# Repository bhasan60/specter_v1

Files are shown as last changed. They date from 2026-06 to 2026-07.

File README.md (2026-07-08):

## The Story Behind Specter V1
Welcome to the Specter V1! This is a custom 9-key macropad that I designed from the ground up. I wanted a dedicated board just for fun and maybe some custom shortcuts, but more importantly, I wanted to challenge myself to handle every single step of the hardware and software design process.

While I have a lot of experience with 3D modeling in Onshape, designing a custom 2-layer PCB from scratch in KiCad was a massive learning experience for me. It was fun though :)

## Hardware & Features
* **The Brain:** The whole board is powered by a Seeed Studio XIAO RP2040.
* **Inputs & Control:** It features 9 mechanical switches and a tactile rotary encoder.
* **Display:** I integrated a small OLED screen at the top to display certain GIFs or random stuff.
* **Custom PCB:** The board is a custom 2-layer design. To give it a personal touch, I added a custom New York Knicks logo to the front silkscreen to rep my city!
* **Enclosure:** The physical case is a custom two-part 3D-printed shell I modeled in Onshape. It is designed to fit snugly around the components and is secured together using M3 screws.
* **Firmware:** The macropad is fully programmable using QMK. 

## Screenshots
Overall Hackpad:



Schematic:



PCB:




Case:


I plan on fitting the two parts of the case together by threading the M3 screws into them.

## Bill of Materials (BOM)
* 1x Seeed Studio XIAO RP2040
* 9x Mechanical Switches
* 9x 1N4148 Diodes
* 1x Rotary Encoder (with push-button)
* 1x OLED Display
* 3D Printed Case (Top and Bottom)

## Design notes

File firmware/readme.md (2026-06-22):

# specter_v1

specter_v1

*A short description of the keyboard/project*

* Keyboard Maintainer: [Belal Hasan](https://github.com/bhasan60)
* Hardware Supported: *The PCBs, controllers supported*
* Hardware Availability: *Links to where you can find this hardware*

Make example for this keyboard (after setting up your build environment):

    make specter_v1:default

Flashing example for this keyboard:

    make specter_v1:default:flash

See the [build environment setup](https://docs.qmk.fm/#/getting_started_build_tools) and the [make instructions](https://docs.qmk.fm/#/getting_started_make_guide) for more information. Brand new to QMK? Start with our [Complete Newbs Guide](https://docs.qmk.fm/#/newbs).

## Bootloader

Enter the bootloader in 3 ways:

* **Bootmagic reset**: Hold down the key at (0,0) in the matrix (usually the top left key or Escape) and plug in the keyboard
* **Physical reset button**: Briefly press the button on the back of the PCB - some may have pads you must short instead
* **Keycode in layout**: Press the key mapped to `QK_BOOT` if it is available

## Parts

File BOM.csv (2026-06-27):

Quantity | Component | Notes
1 | Seeed Studio XIAO RP2040 | Main microcontroller
9 | Mechanical Switches | Keyboard switches
9 | 1N4148 Diodes | Matrix diodes
1 | Rotary Encoder (with push-button) | Encoder with click
1 | OLED Display | Screen
1 | 3D Printed Case (Top and Bottom) | Enclosure

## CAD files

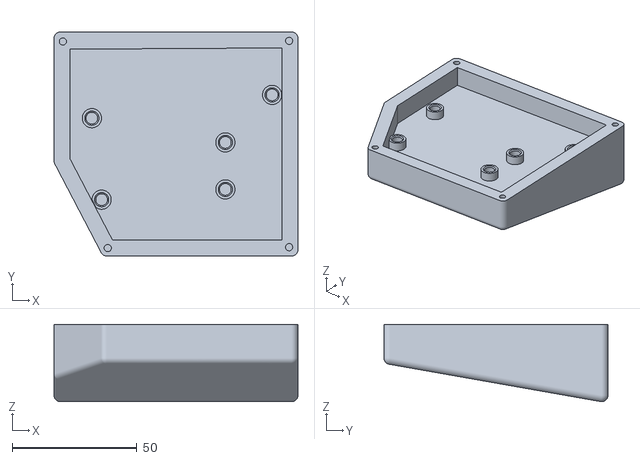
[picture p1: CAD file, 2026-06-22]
production/BOTTOM.stl
97.6 x 89.6 x 30.9

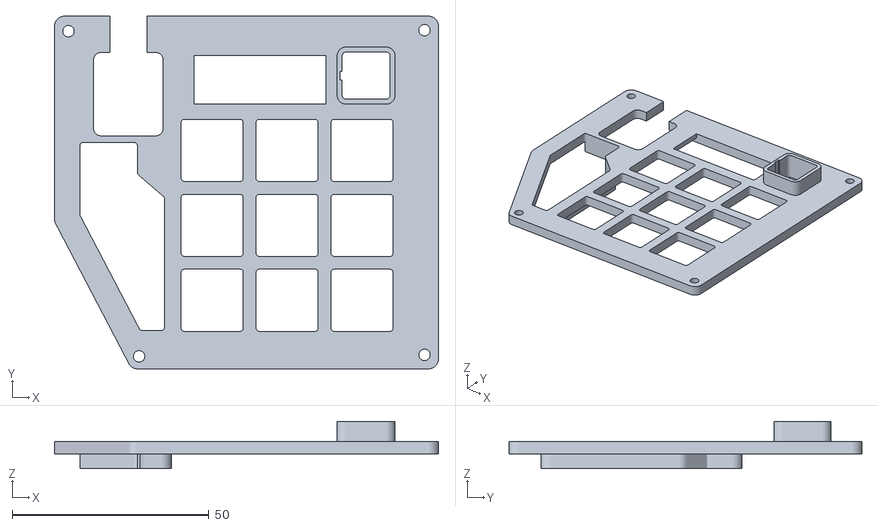
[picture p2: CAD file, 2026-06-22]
production/TOP.stl
97.6 x 89.6 x 12.0

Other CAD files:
cad/specter_v1.3mf

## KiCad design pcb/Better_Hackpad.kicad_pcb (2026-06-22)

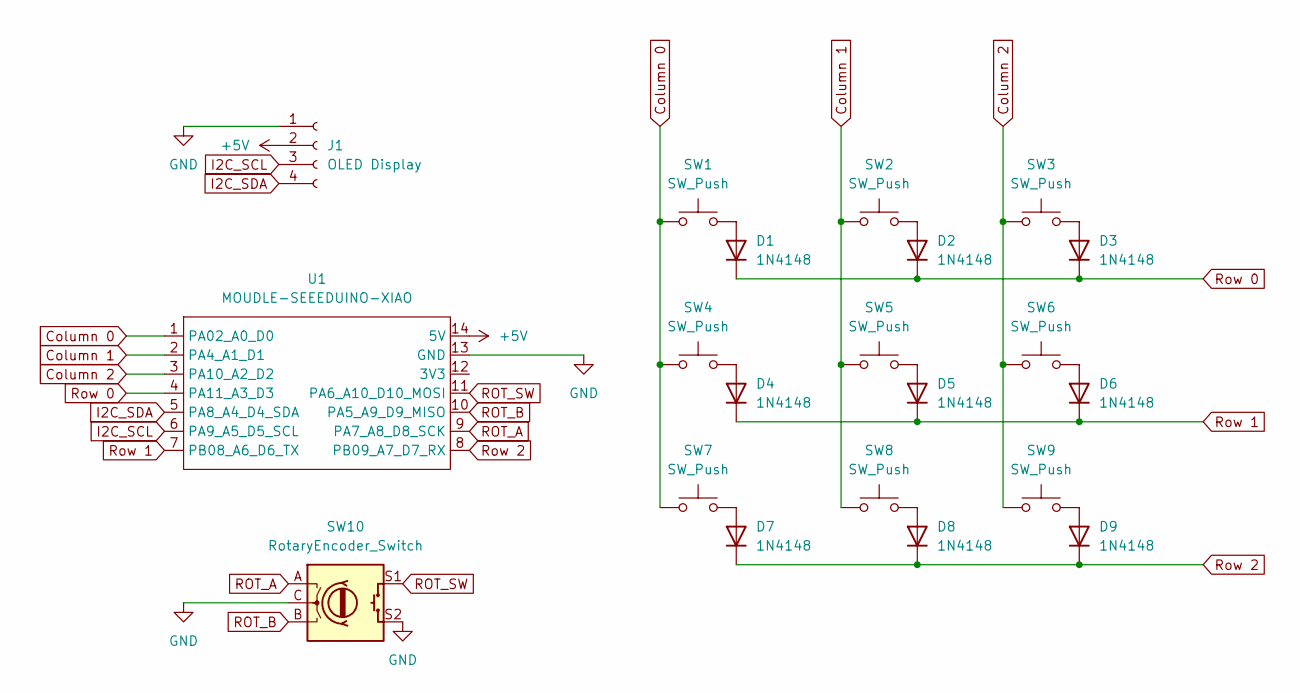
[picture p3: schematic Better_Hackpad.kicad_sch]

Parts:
D1, D2, D3, D4, D5, D6, D7, D8, D9: 1N4148; D_DO-35_SOD27_P7.62mm_Horizontal
J1: OLED Display; SSD1306-0.91-OLED-4pin-128x32
SW1, SW2, SW3, SW4, SW5, SW6, SW7, SW8, SW9: SW_Push; SW_Cherry_MX_1.00u_PCB
SW10: RotaryEncoder_Switch; RotaryEncoder_Alps_EC11E-Switch_Vertical_H20mm
U1: MOUDLE-SEEEDUINO-XIAO; XIAO-Generic-Hybrid-14P-2.54-21X17.8MM

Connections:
+5V: J1.2, U1.14 (5V)
Column 0: SW1.1, SW4.1, SW7.1, U1.1 (PA02_A0_D0)
Column 1: SW2.1, SW5.1, SW8.1, U1.2 (PA4_A1_D1)
Column 2: SW3.1, SW6.1, SW9.1, U1.3 (PA10_A2_D2)
GND: J1.1, SW10.C, SW10.S2, U1.13 (GND)
I2C_SCL: J1.3, U1.6 (PA9_A5_D5_SCL)
I2C_SDA: J1.4, U1.5 (PA8_A4_D4_SDA)
unnamed: D1.2 (A), SW1.2
unnamed: D2.2 (A), SW2.2
unnamed: D3.2 (A), SW3.2
unnamed: D4.2 (A), SW4.2
unnamed: D5.2 (A), SW5.2
unnamed: D6.2 (A), SW6.2
unnamed: D7.2 (A), SW7.2
unnamed: D8.2 (A), SW8.2
unnamed: D9.2 (A), SW9.2
ROT_A: SW10.A, U1.9 (PA7_A8_D8_SCK)
ROT_B: SW10.B, U1.10 (PA5_A9_D9_MISO)
ROT_SW: SW10.S1, U1.11 (PA6_A10_D10_MOSI)
Row 0: D1.1 (K), D2.1 (K), D3.1 (K), U1.4 (PA11_A3_D3)
Row 1: D4.1 (K), D5.1 (K), D6.1 (K), U1.7 (PB08_A6_D6_TX)
Row 2: D7.1 (K), D8.1 (K), D9.1 (K), U1.8 (PB09_A7_D7_RX)

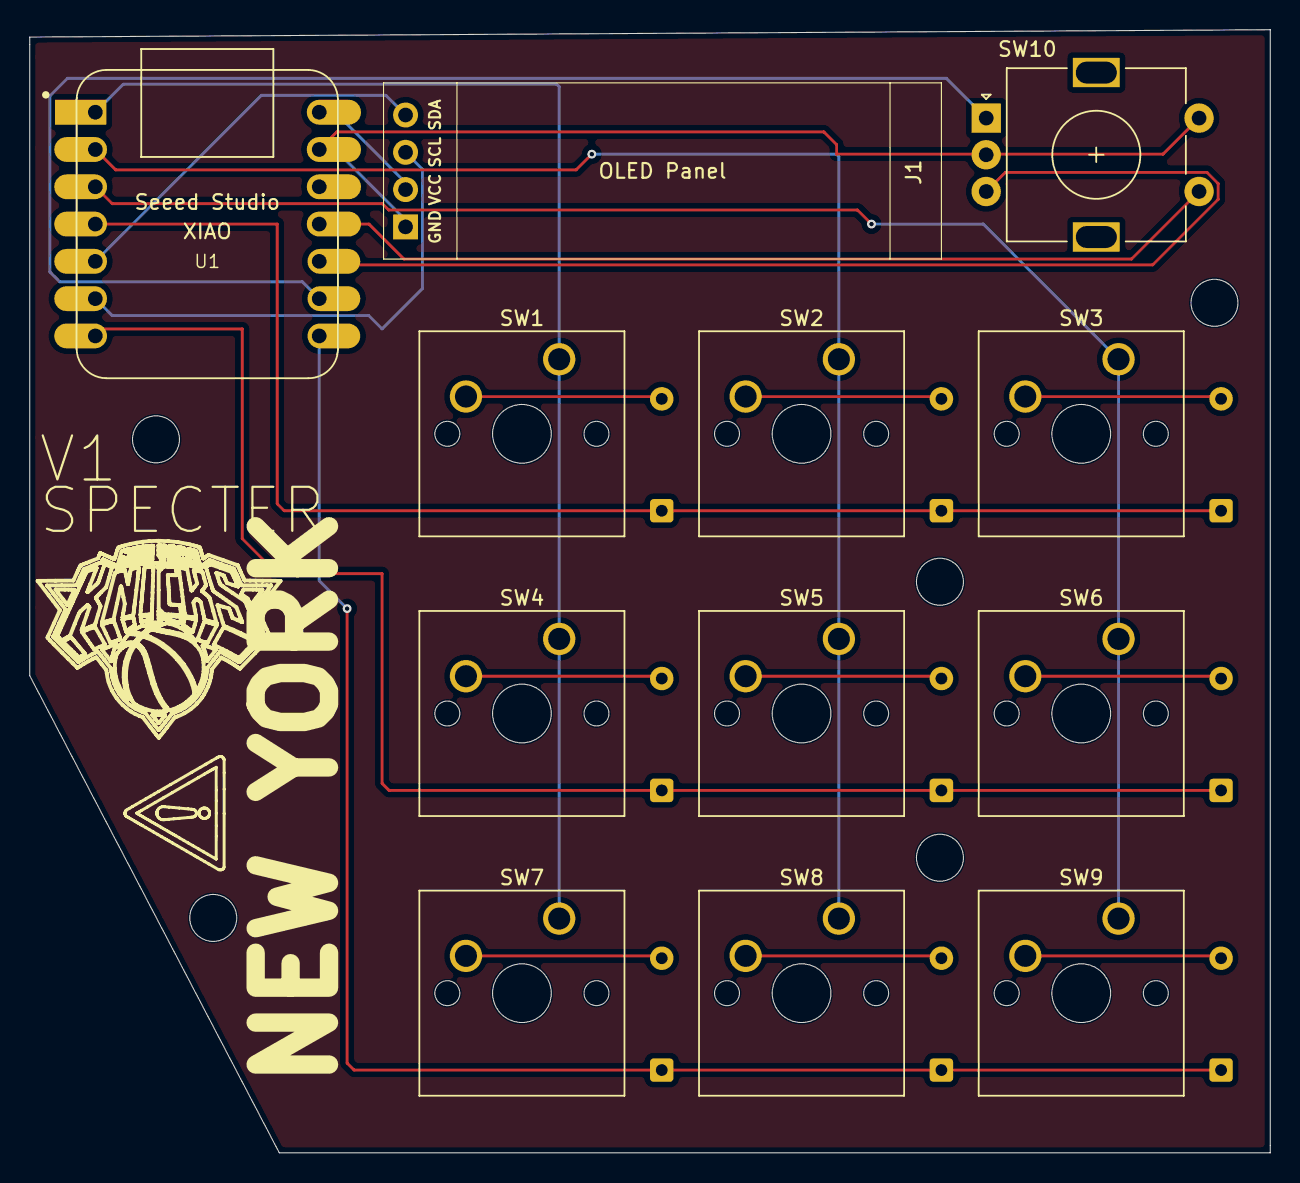
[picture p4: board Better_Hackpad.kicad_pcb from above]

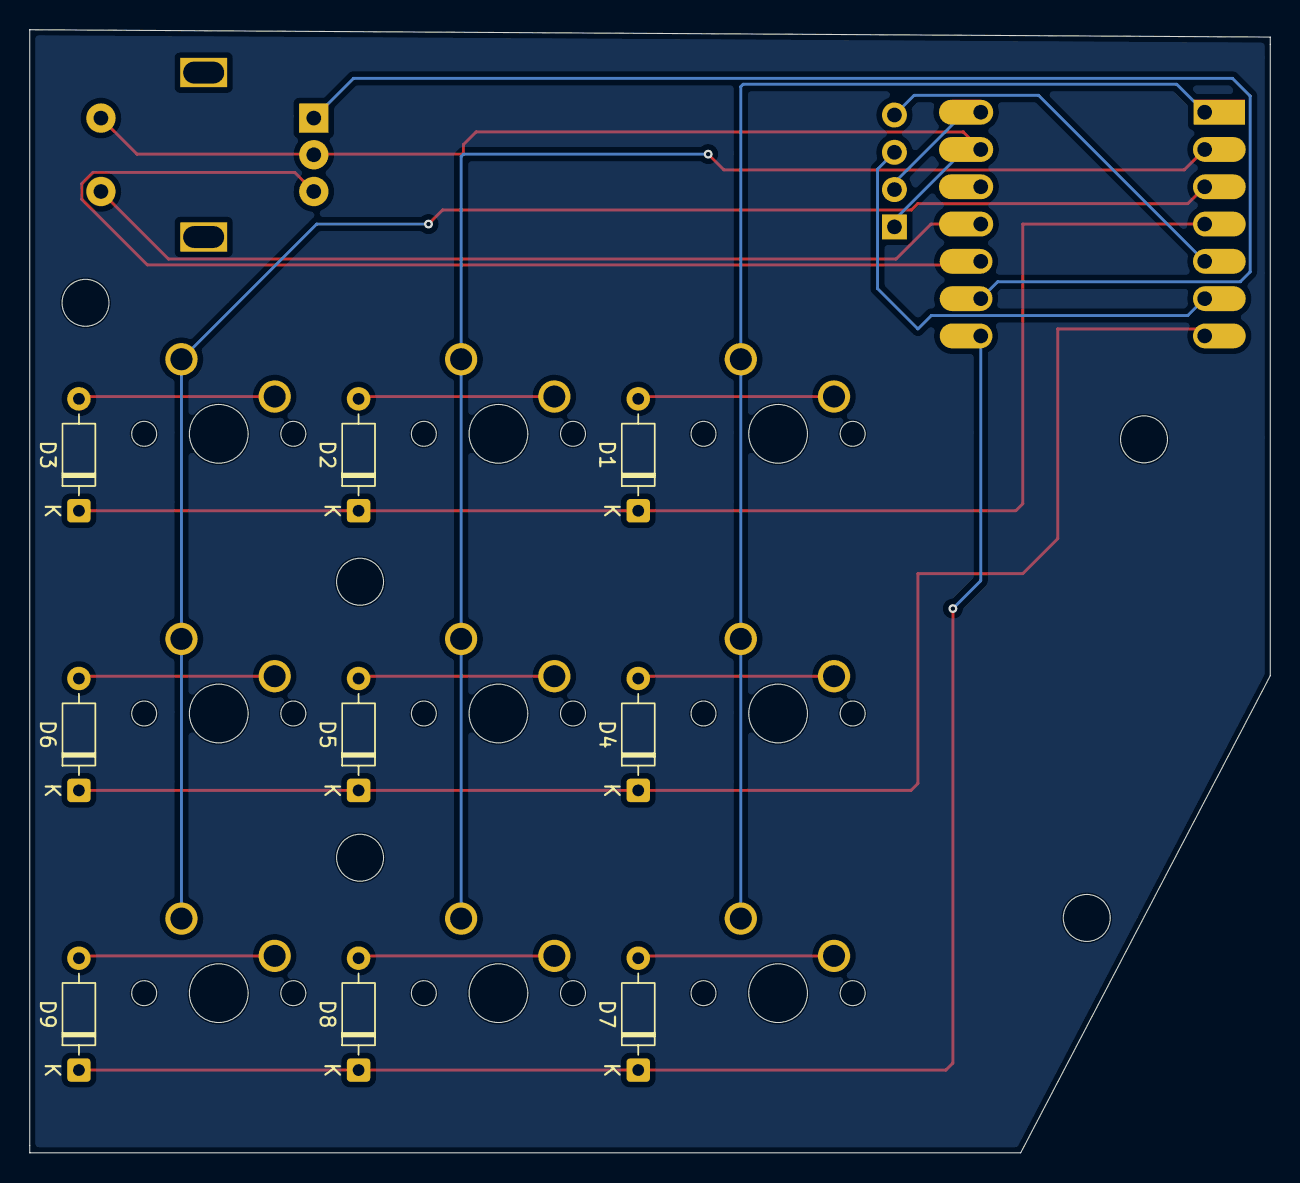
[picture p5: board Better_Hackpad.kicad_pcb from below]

Board: 2 copper layers, 84.5 x 76.5 mm, 21 parts (9 on the bottom side), 22 nets.

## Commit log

2026-06-22 Update README with project details and BOM
    Added project description, screenshots, and BOM.
2026-06-22 Update README with images and case description
    Added images and descriptions for overall hackpad, schematic, PCB, and case.
2026-06-22 Replace schematic and PCB images in README
    Updated schematic and PCB images in README.
2026-06-22 Update README with images and BOM section
    Added images and information for overall hackpad, schematic, PCB, and case.
2026-07-08 Edit README to simplify PCB design description
    Removed a sentence about the learning experience in PCB design.
